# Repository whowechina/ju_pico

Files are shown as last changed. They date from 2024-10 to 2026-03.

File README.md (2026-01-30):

# Ju Pico - Jubeat Style Mini Controller
[点这里可以切换到中文版](README_CN.md)

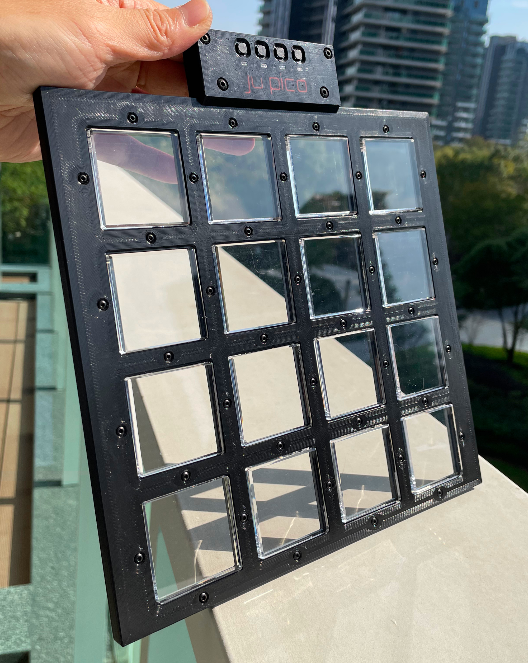
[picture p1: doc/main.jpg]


Features:
* There're two versions. Ju Pico is designed for 15.6" portable monitor, Ju Pico+ is designed for 21.5" monitor.
* It's small but closely replicates the feel of the arcade.
* Can be placed in 4 different orientations (rotations).
* Command line for configurations.
* All source files open.

Thanks to many respectful guys/companies who made their tools or materials free or open source (KiCad, OnShape, InkScape, Raspberry things).

Special thanks to community projects and developers.
And also these projects:
* RP_Silicon_KiCad: https://github.com/HeadBoffin/RP_Silicon_KiCad
* Type-C: https://github.com/ai03-2725/Type-C.pretty

## My Other Projects
You can check out my other cool projects.

           

* Popn Pico: https://github.com/whowechina/popn_pico
* IIDX Pico: https://github.com/whowechina/iidx_pico
* IIDX Teeny: https://github.com/whowechina/iidx_teeny
* Chu Pico: https://github.com/whowechina/chu_pico
* Mai Pico: https://github.com/whowechina/mai_pico
* Diva Pico: https://github.com/whowechina/diva_pico
* AIC Pico: https://github.com/whowechina/aic_pico
* Groove Pico: https://github.com/whowechina/groove_pico
* Geki Pico: https://github.com/whowechina/geki_pico
* Musec Pico: https://github.com/whowechina/musec_pico
* Ju Pico: https://github.com/whowechina/ju_pico

## **Disclaimer** ##
I made this project in my personal time with no financial benefit or sponsorship. I will continue to improve the project. I have done my best to ensure that everything is accurate and functional, there's always a chance that mistakes may occur. I cannot be held responsible for any loss of your time or money that may result from using this open source project. Thank you for your understanding.

## About the License
It's CC-NC. So DIY for yourself and for your friend, don't make money from it. And plagiarism that doesn’t even dare to mention the original author is not acceptable. Please note that pooling orders and group buying for raw materials is acceptable. Selling off any leftover components without profit is also acceptable.

If you're interested in buying from me, or for commercial use, please contact me (Discord, QQ group, Wechat group or leave your contact in issue section).

## My Discord Invitation
https://discord.gg/M8f2PPQFEA

## HOW TO BUILD JU PICO
### PCB and Components
* Go JLCPCB and make order with the gerber zip files (latest `Production\PCB\ju_io_xxx.zip` and `Production\PCB\ju_button_xxx.zip`), regular FR-4 board, black color, **1.6mm** thickness. For Ju Pico+, please use `button215` version.
* 1x Raspberry Pico Pi Pico or pin-to-pin compatible clones (U1).  
  https://www.raspberrypi.com/products/raspberry-pi-pico
* 1x USB Type-C socket (918-418K2023S40001 or KH-TYPE-C-16P)
* 4x WS2812B-3528 RGB LEDs.
* 4x Alps SKPMAPE010 6.0×5.9mm tactile switch in black, Panasonic EVQP1K05M works too, but it only comes in a white version.  
  https://tech.alpsalpine.com/e/products/detail/SKPMAPE010/
* 1x 0603 0.1uF (0.1~1uF all fine) capacitor (C1).
* 2x 0603 5.1kohm resistors (R1, R2) for the USB.
* 8x JST-SH1.0 5-pin SMD connectors (J1 to J4 on IO PCB, and 4 others on button PCBs).
* 1x JST-SH1.0 3-pin SMD connector (J5), optional for future HID light expansion.
* 4x JST-SH1.0 dual-end 5-pin cables (pin 1 to pin 1 mapping): 2 cables of 20cm length, and 2 cables of 30cm length.
* 64x Silicone rubber buttons, **6mm\*7mm**, **4mm** height, with 2 legs. Buy soft (lower actuation force) ones if possible. It looks like this:  
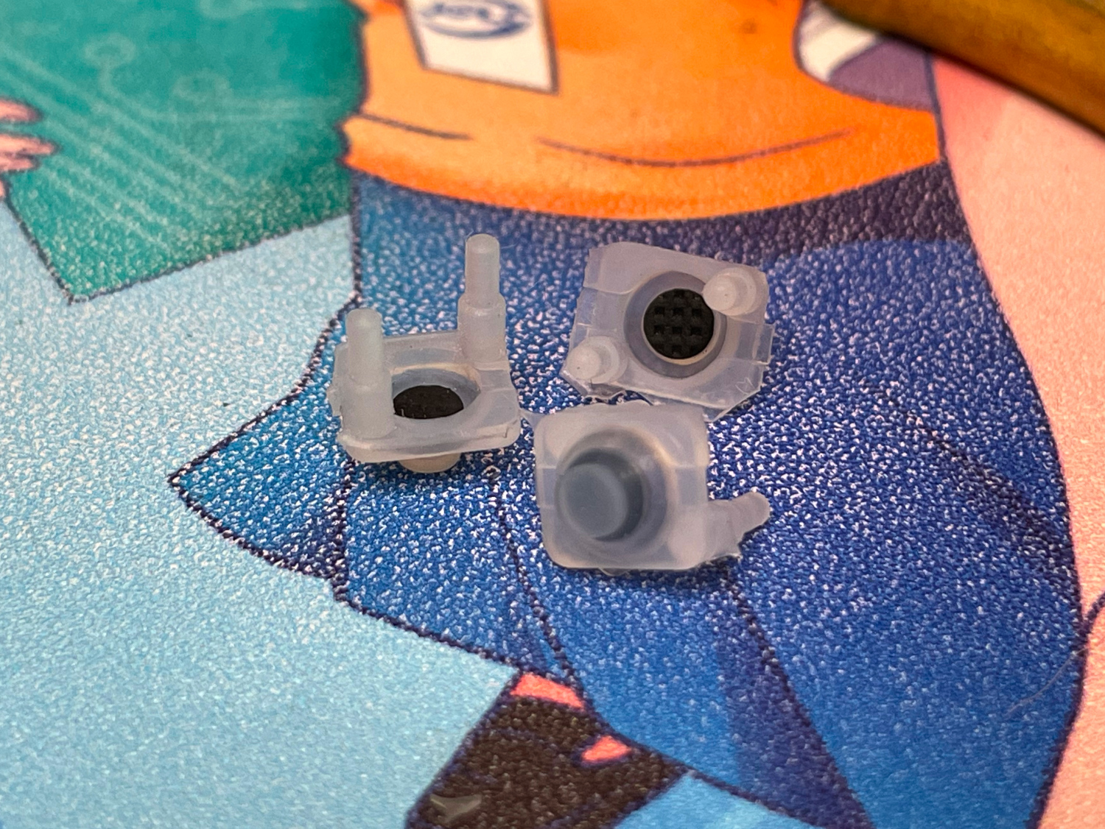
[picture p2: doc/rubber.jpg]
  
* This is how the I/O board looks after soldering.  
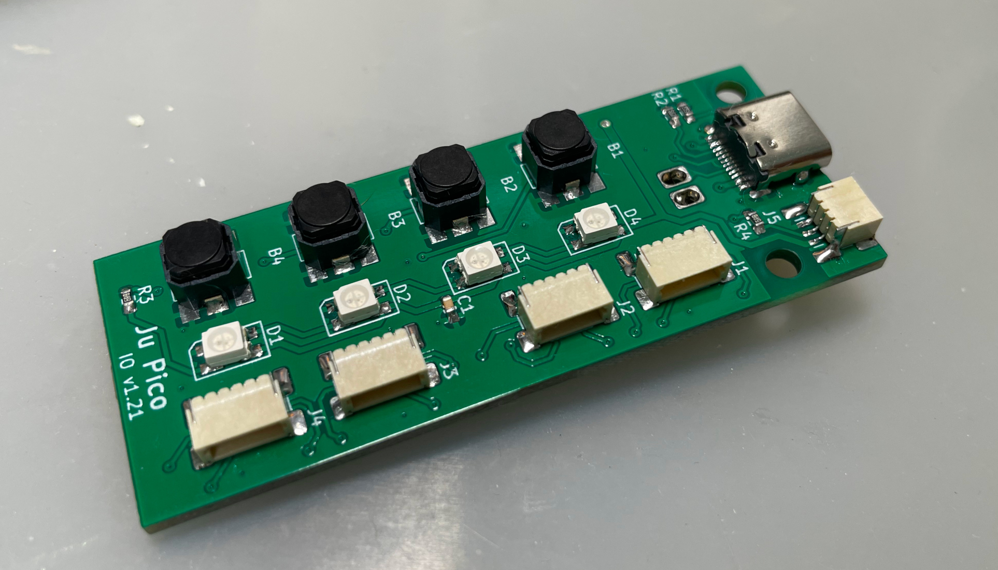
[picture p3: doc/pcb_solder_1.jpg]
    
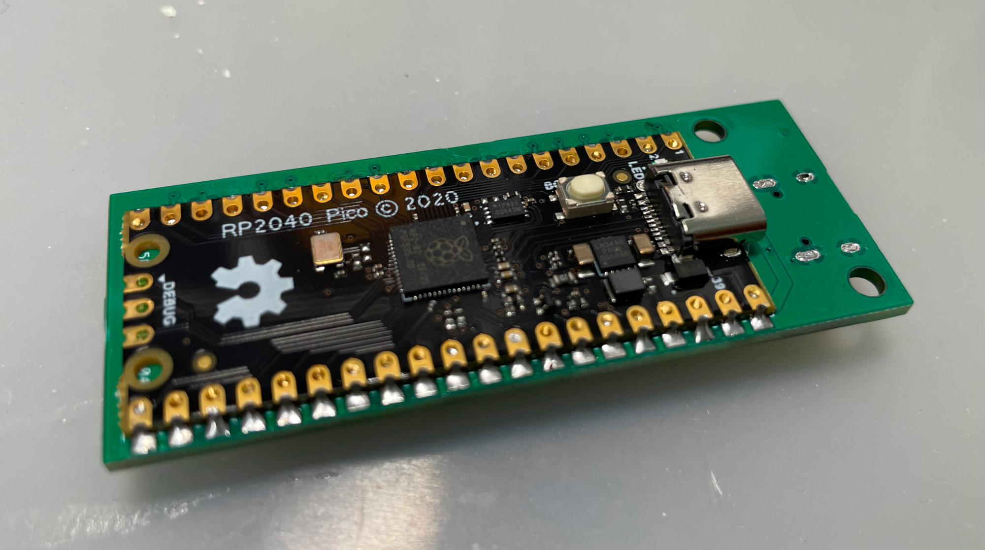
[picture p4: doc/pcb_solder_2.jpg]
  
* Becareful of 2 pin holes. It's a common oversight to either forget to solder them or to leave air bubbles during the process. To avoid this, solder slowly from one side of the hole, using minimal solder wire and a generous amount of flux.  
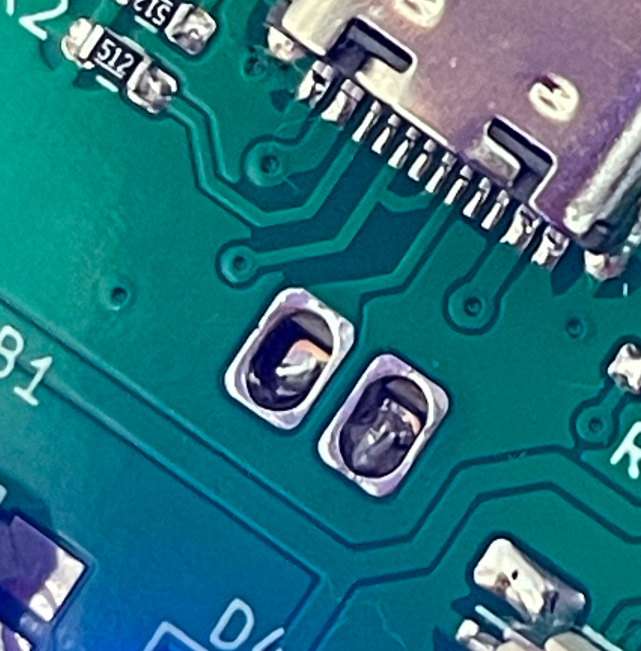
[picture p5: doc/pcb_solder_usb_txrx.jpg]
  

### Test the IO PCB
* You can test the PCB now, put the firmware in IO PCB.
* All 4 RGB LEDs should light up in a rainbow pattern.
* LEDs responds to the the leftmost button, indicating current orientation.
* Ju Pico should be recognized as a USB HID device, here's the test page.  
  https://greggman.github.io/html5-gamepad-test/
* Connect the 4 button PCBs to the IO PCB, and use one rubber button to test the button contacts on the PCB, you'll see the status change in said HID test page.

### Button Cap
Ju Pico has 16 buttons, so you need to order 16 button caps.

They are made of clear acrylic, measuring 40mm x 40mm with a corner radius of 1-1.5mm and a thickness of 5mm. All these parameters are IMPORTANT and should be followed closely. A polished bevel of **1.5-2mm** on top edges gives a better feel.

Here's what it looks like.  
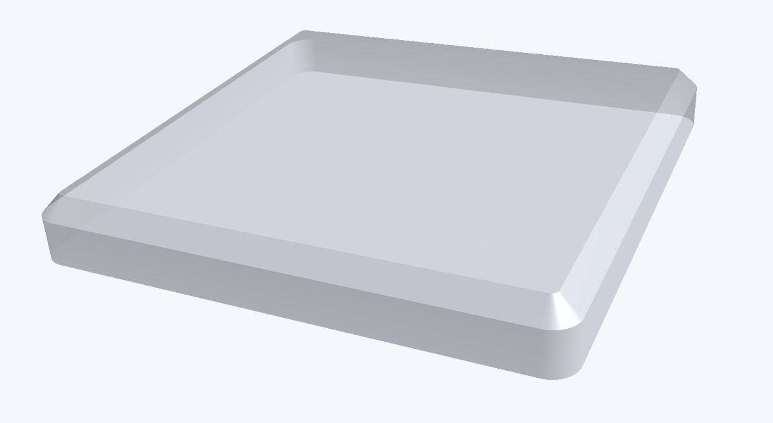
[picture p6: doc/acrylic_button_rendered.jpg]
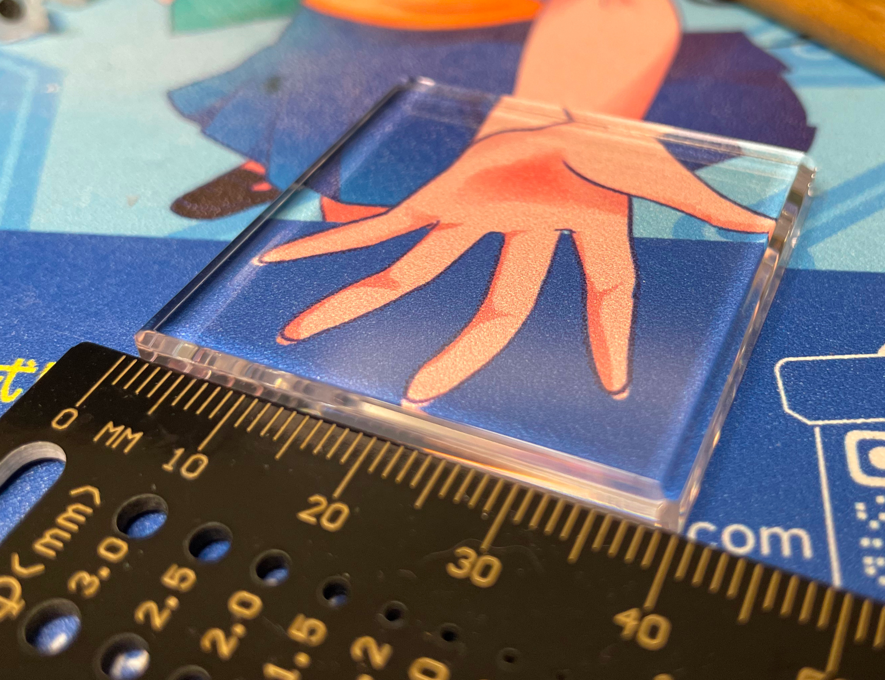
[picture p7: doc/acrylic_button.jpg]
 

### 3D Printing
#### Printing parameters
* PLA (recommended) or PETG.
* Layer height: 0.2mm.
* Walls: 5.
* Infill: >=80%.
* Support: Yes, better with special support material.
* Glue on bed: Yes, it prevents corner warping.
* Files are always in millimeter unit, not inch.

#### Parts
* Note: if you want to build Ju Pico+, please use the files with "+" in the filename.
* You have 3 options for the Frame part, heatset insert version is recommended.
  * Screws are threaded into heatset inserts: `Production\3DPrint\ju_pico_frame_inserts.stl`, black. Please install the heat-set inserts first.
  * Screws are directly threaded into the printed material: `Production\3DPrint\ju_pico_frame.stl`, black. Assembly is easier but the screws may wear out the material over time.
  * Screws are threaded into the hex nuts: `Production\3DPrint\ju_pico_frame_hexnut.stl`, black. Assembly is a bit more complicated but the screws won't wear out the material.
* Panel: `Production\3DPrint\ju_pico_panel.stl`, black, print up-side-down with support (use special support material if possible).
* Banner: `Production\3DPrint\ju_pico_banner.3mf`, multi-color, print up-side-down, mainbody is black, LED windows are transparent, logos are red or orange, use special support material if possible.
* 16x Button Seats: `Production\3DPrint\ju_pico_button_seat_*.stl`, black, print up-side-down to avoid overhanging. Choose the one that fits your button cap.
* All together, they look like these.  
  
* Note: Files with "bambu" in the name are project files prepared for Bambu Studio.
* CAUTION: Do not mix use files before and after December 2024, as I made some incompatible changes in early December 2024.

### CNC Aluminum Processing (Optional, only available for Ju Pico)
* If you're into that sleek metal look and don't mind splurging a bit, you can get the frame, panel, and banner parts CNC machined from aluminum.
* Sandblasting and anodizing can be chosen to make it look even better.
* The STEP files are in `Production\CNC` folder, the 2D DWG file is the thread tapping drawing for the frame part.
* You need to 3D print `Production\3DPrint\ju_pico_led_diffuser_for_cnc.stl` for LED diffusion, use transparent material.

### Assembly
#### Other Materials Needed
1. Clear soft/flexible glue or UV curing glue. WARNING: Avoid using any cyanoacrylate-based glue, such as 502. Any glue with a similar smell should also be avoided, as they will leave white smoke marks on the acrylic.
2. 40x **M2\*6mm** (for regular frame) or **M2\*7mm** (for hex nut frame or heatset insert frame) screws, black, for the panel.
3. 4x **M3\*8mm** screws, black, for the banner.
4. 40x **M2** hex nuts (only for hex nut frame version).
5. 40x **M2\*3mm\*3mm** heat-set inserts (only for heatset insert frame version).

### Step by Step
1. Glue the button bodies to the button seats. Be careful don't let the glue ruin the acrylic. See the "Caution" section below for more details.  
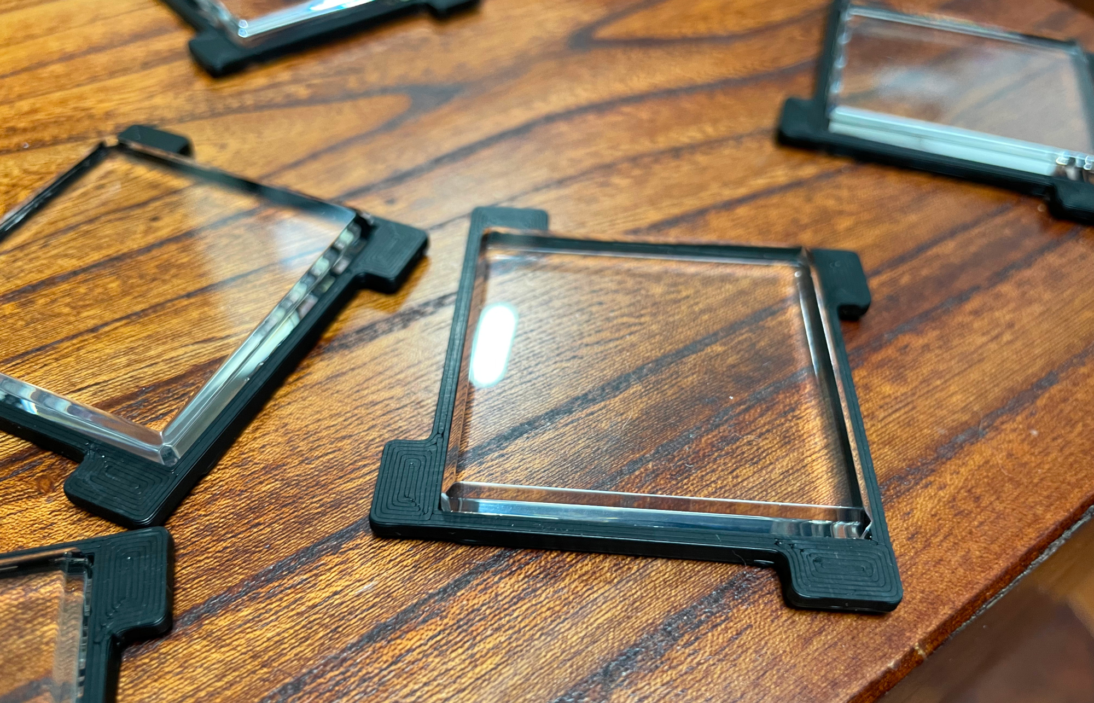
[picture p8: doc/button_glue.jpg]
   
2. Insert the silicone rubber buttons into the button PCBs. Ensure to pull the legs so that the button sits perfectly flush against the PCB.  
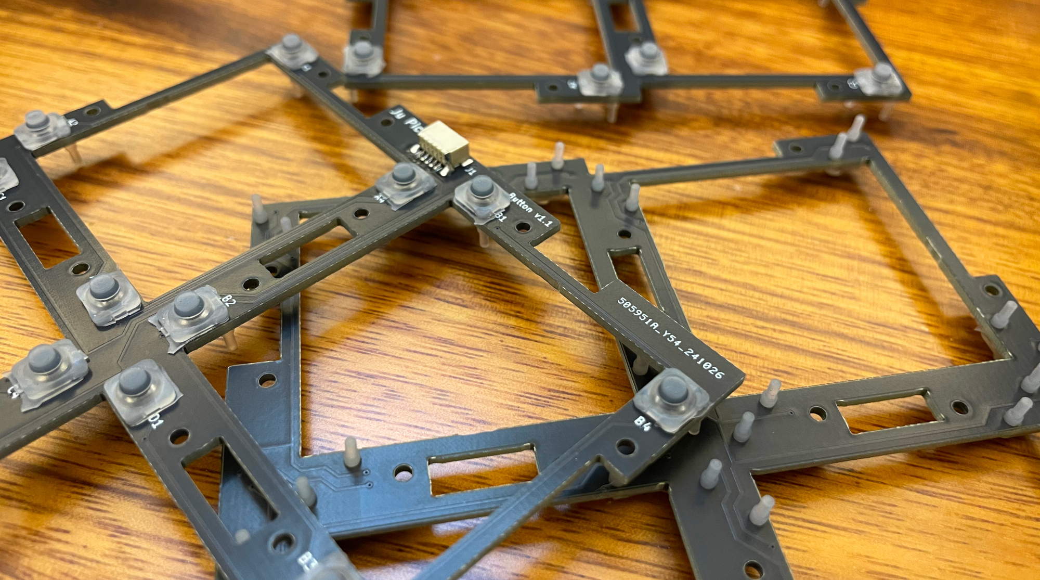
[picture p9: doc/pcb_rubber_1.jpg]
   
3. Use a sharp side cutter to trim the legs of the rubber buttons so that they are flush with the PCB, leaving no protruding parts.  
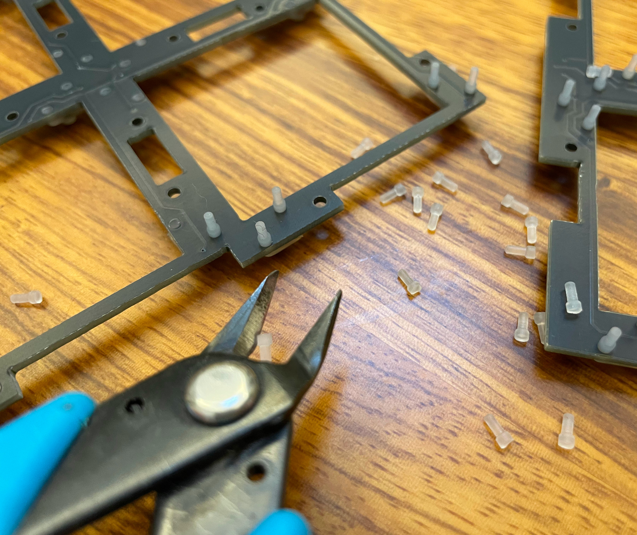
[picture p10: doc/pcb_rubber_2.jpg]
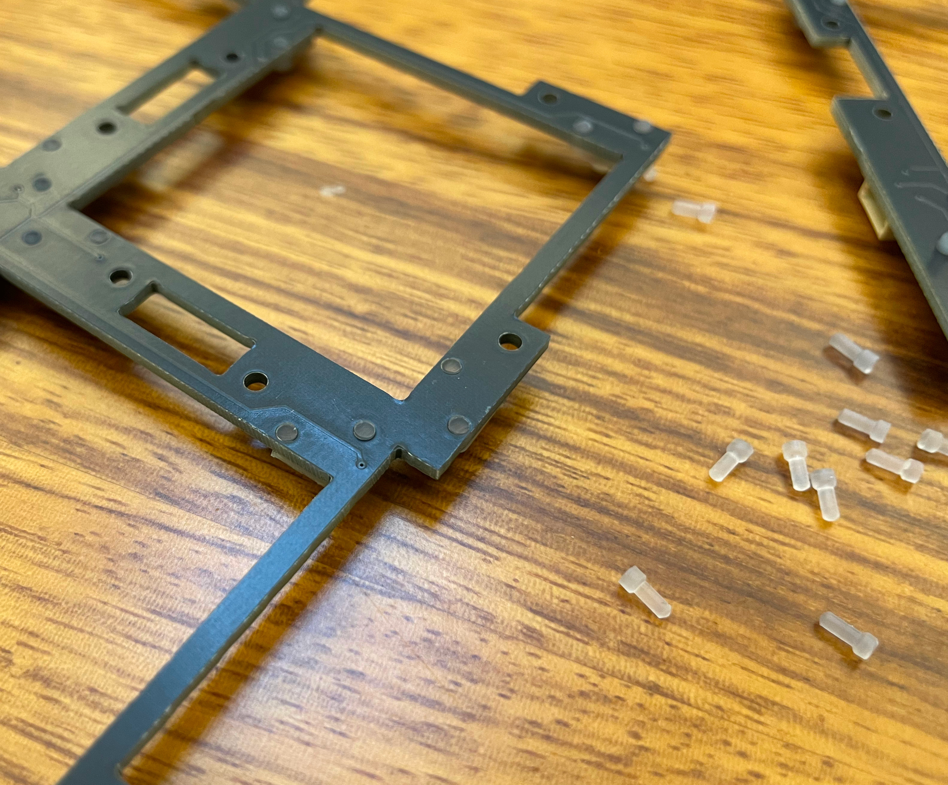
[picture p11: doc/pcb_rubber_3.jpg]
    
4. Put button PCBs into the frame part and use the cables to connect them to the IO PCB.  
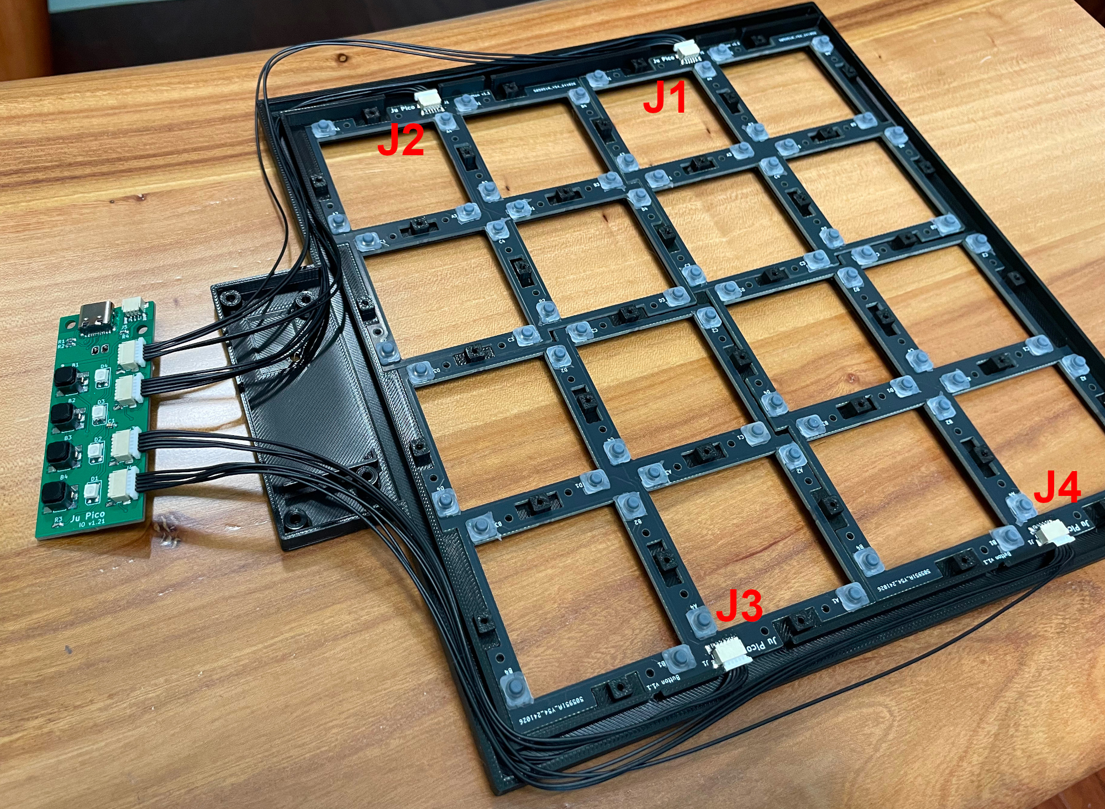
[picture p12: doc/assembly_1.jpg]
   
5. Arrange the cables and make them fit in the cable slots.  
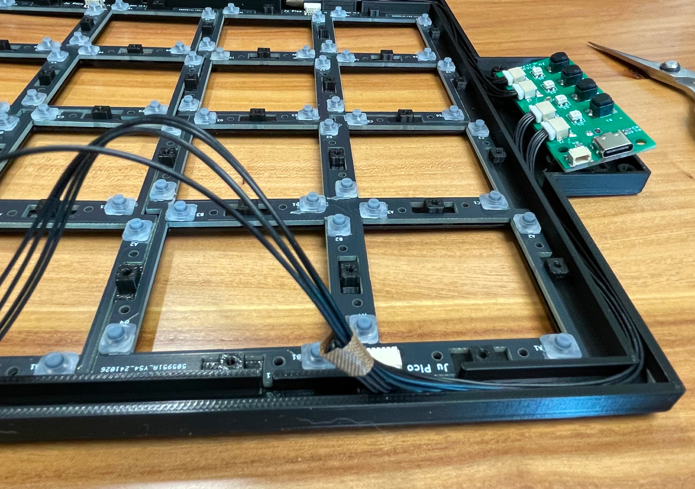
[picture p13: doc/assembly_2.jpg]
   
6. If you arrange them well, it will look very neat.  
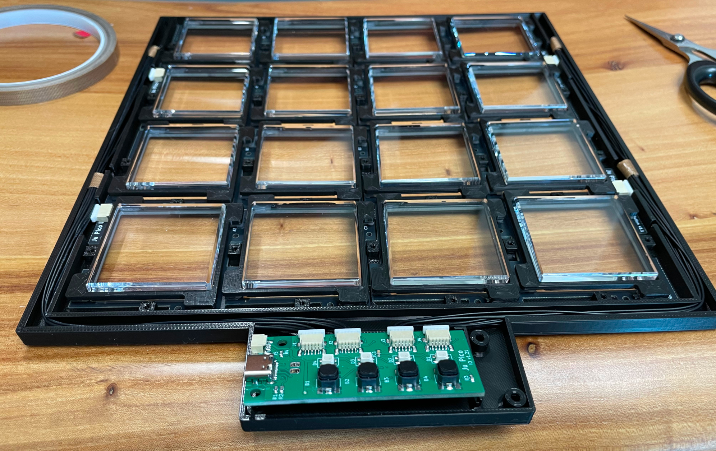
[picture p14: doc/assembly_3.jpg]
   
7. Gently put the finished buttons onto the button PCBs.  
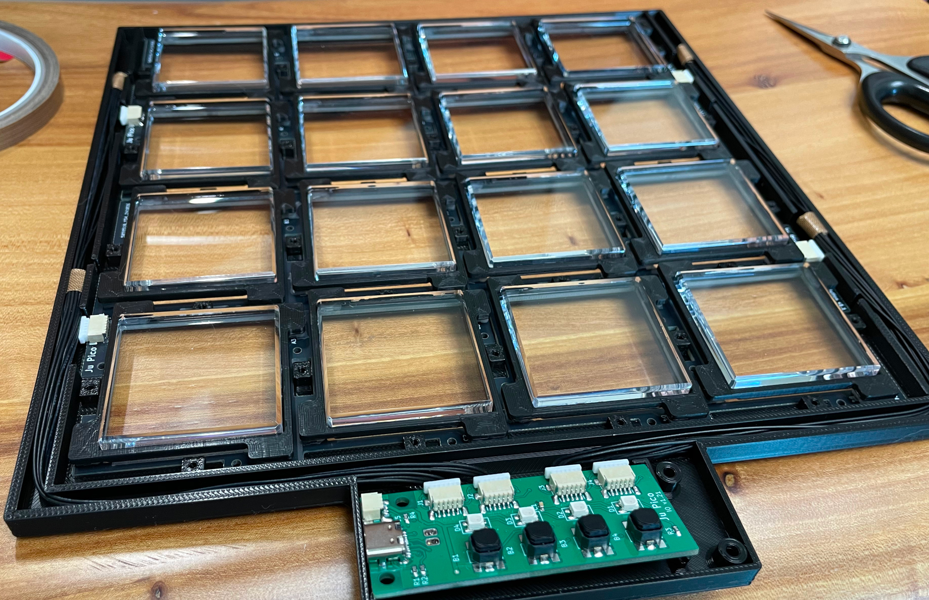
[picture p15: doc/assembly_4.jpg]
   
8. Attach the panel part and secure it with (a lot) M2 screws. Be very careful, 3D print materials are fragile and sensitive to heat. So screw slowly, especially when using a power screwdriver, as the threads in the plastic can easily strip. Lastly put on the banner part and use M3 screws to fix it. And there you go!  
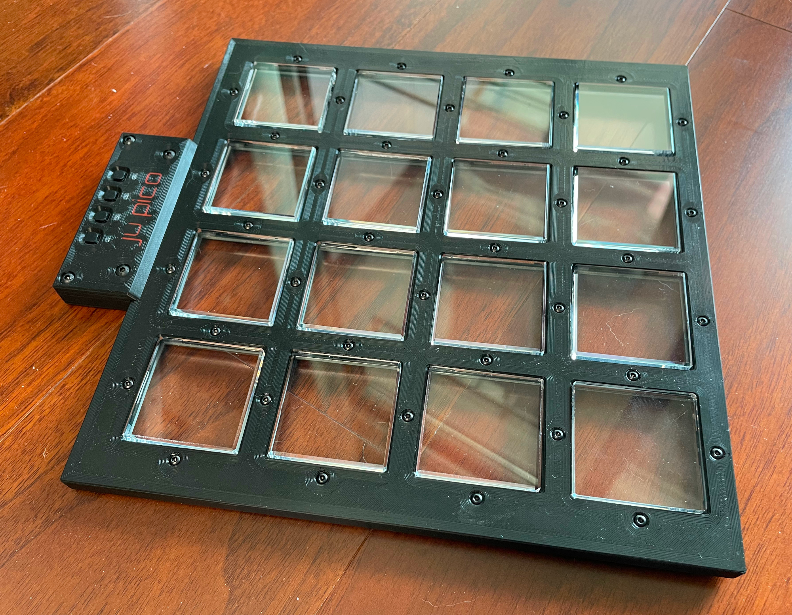
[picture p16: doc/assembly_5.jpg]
   

#### Caution
Each 3D printer and filament has its own tolerance, as does the acrylic cutting service. Therefore, I've created multiple versions of the button seat. You can try them and select the one that fits your acrylic button cap perfectly.

## Firmware
* UF2 file is in `Production\Firmware` folder.
* For the new build, hold the BOOTSEL button while connect the USB to a PC, there will be a disk named "RPI-RP2" showed up. Drag the UF2 firmware binary file into it. That's it. There's a small hole at the bottom side of the Ju Pico, it is facing right to the BOOTSEL button.
* If it's already running Ju Pico firmware, you can either use "update" in command line or hold down at least 4 buttons while connecting to USB to enter update mode.
* To access the command line, you can use this Web Serial Terminal to connect to the USB serial port of the Ju Pico. (Note: "?" is for help)  
  https://googlechromelabs.github.io/serial-terminal/

### Usage
* Attach the Ju Pico to a 15.6-inch portable monitor (or Ju Pico+ to a 21.5-inch monitor) using VHB residue-free adhesive tape. Use 3 to 4 small pieces on the monitor's frame, but avoid placing any on the screen. Position it in the orientation that best suits your needs.
* Press the auxiliary button closest to letter 'j" of the logo "Ju Pico" together with the top left main button in the actual placement to set button order that matches your orientation. Analog joystick position in HID report indicates which side the logo should be. You can use the following website to see the joystick status.  
  https://greggman.github.io/html5-gamepad-test/

## CAD Source File
I'm using OnShape free subscription. It's powerful but it can't archive original designs to local, so I can only share the link here. STL/DXF/DWG files are exported from this online document.  
  https://cad.onshape.com/documents/c70fd7c4cb933fd28c4678b3/w/277dab41d8d592c817e9419a/e/e9cf38ee55134a09b2deb5d6

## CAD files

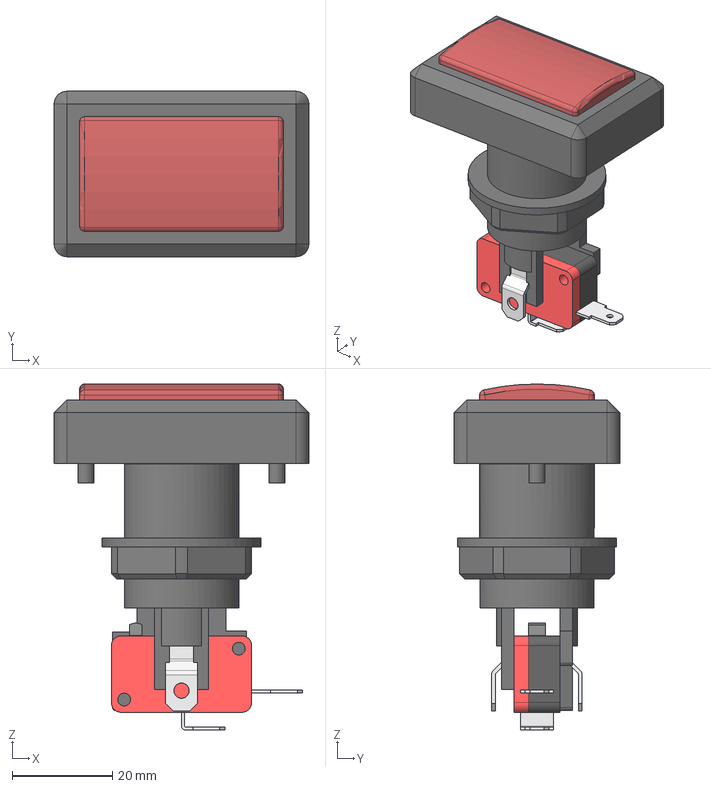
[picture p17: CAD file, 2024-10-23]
PCB/Touch/3dmodels/Credit Button Assy (Groovy).step
50.8 x 33.0 x 69.0 mm
Button
Nut
Switch

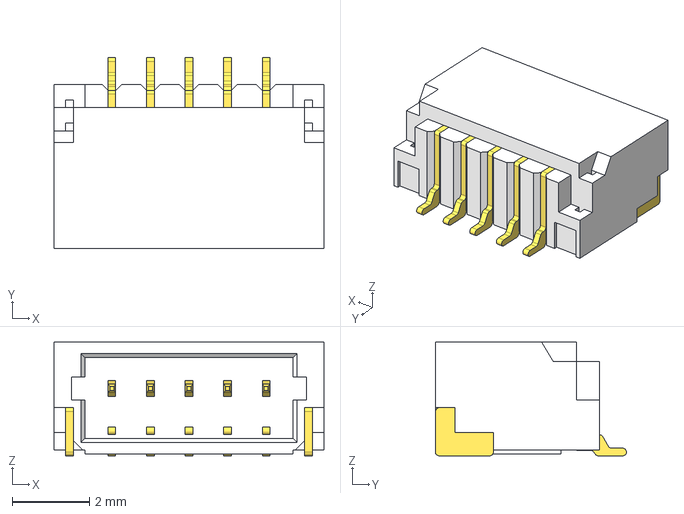
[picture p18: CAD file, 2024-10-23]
PCB/Button/3dmodels/SM5B-SRSS-TB.step
7.00 x 4.95 x 2.95 mm

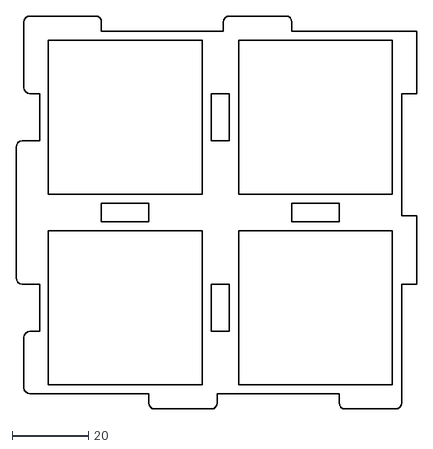
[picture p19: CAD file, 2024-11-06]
PCB/Button/PCB - PCB Cut.dxf
105.2 x 103.2

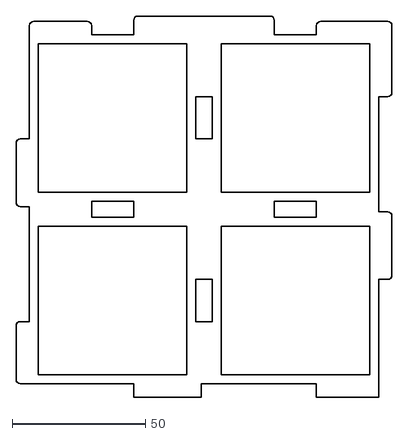
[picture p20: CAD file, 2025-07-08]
PCB/Button215/PCB+ - PCB Cut 215.dxf
141.1 x 143.1

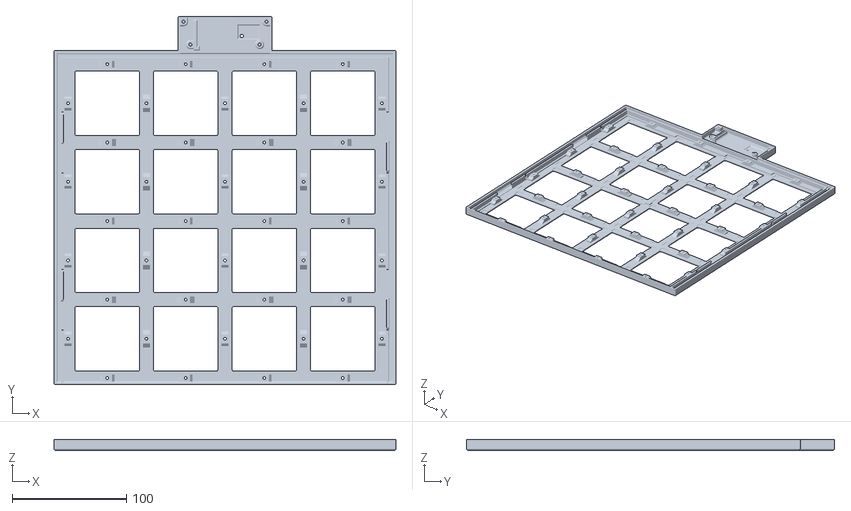
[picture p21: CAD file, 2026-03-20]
Production/3DPrint/ju_pico+_frame_inserts.stl
299.6 x 322.6 x 9.20

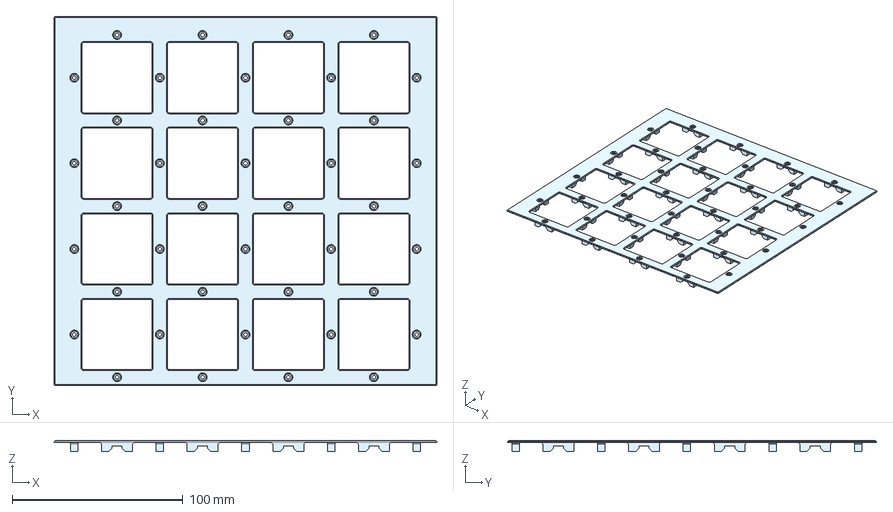
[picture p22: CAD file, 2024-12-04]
Production/CNC/ju_pico_cnc_panel.step
224.0 x 216.0 x 6.20 mm

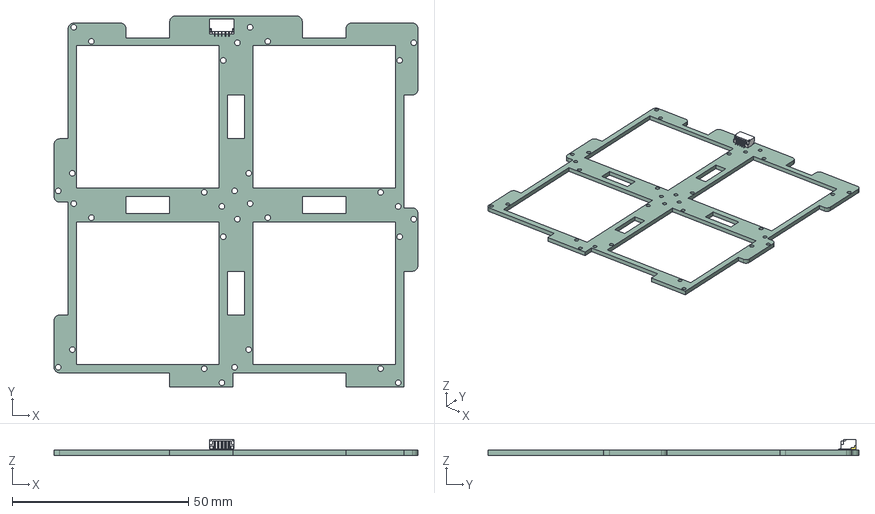
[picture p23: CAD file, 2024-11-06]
PCB/Button/ju_button_3d.step
103.2 x 105.2 x 4.65 mm
SMxB-SRSS-TB
ju_button_PCB

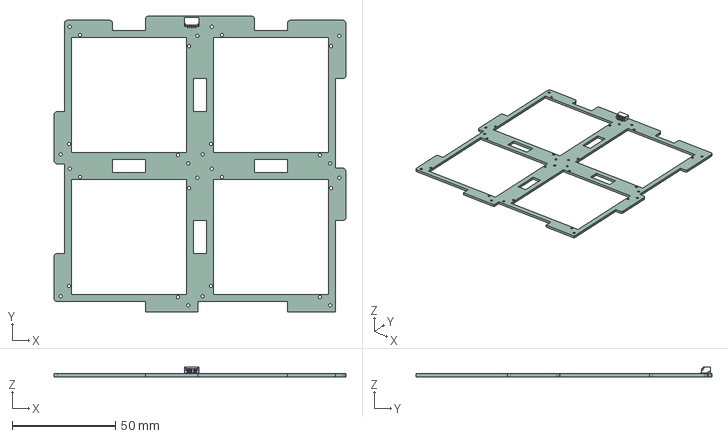
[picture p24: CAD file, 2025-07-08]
PCB/Button215/ju_button215_3d.step
141.1 x 143.1 x 4.59 mm
SM5B-SRSS-TB
ju_button215_PCB

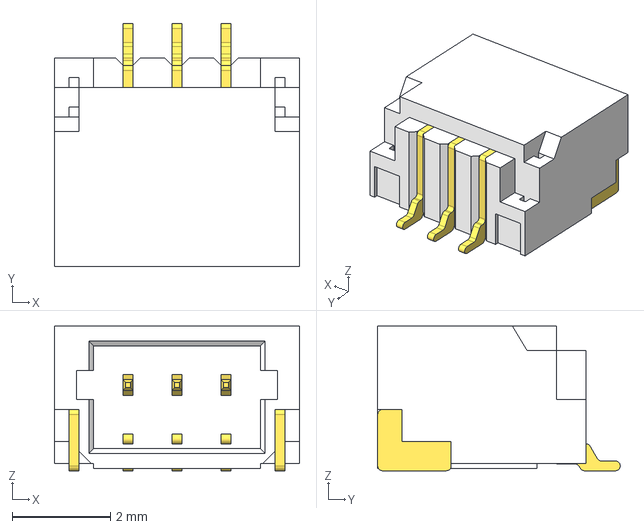
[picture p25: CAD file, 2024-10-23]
PCB/IO/3dmodels/SM3B-SRSS-TB.step
5.00 x 4.95 x 2.95 mm

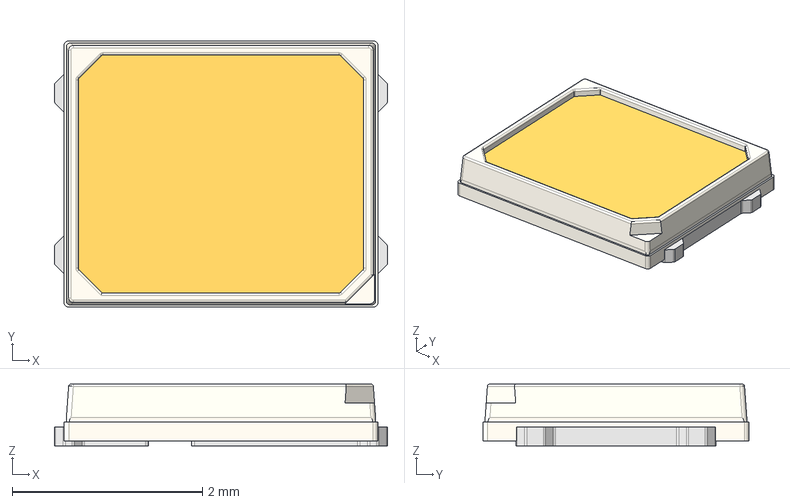
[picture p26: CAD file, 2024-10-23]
PCB/Touch/3dmodels/J 2835.step
3.50 x 2.80 x 0.65 mm

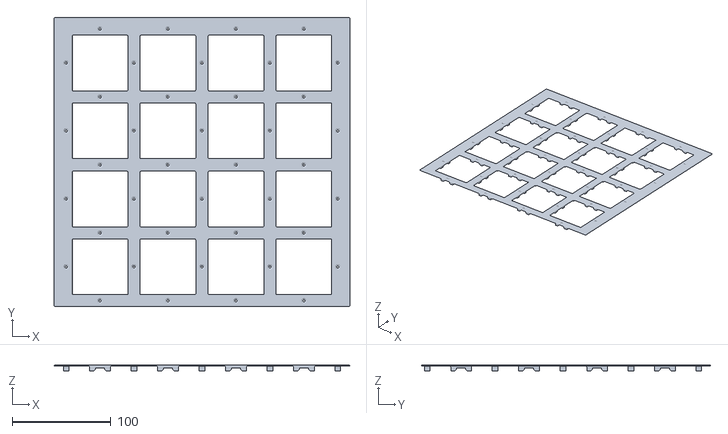
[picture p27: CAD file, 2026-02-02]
Production/3DPrint/ju_pico+_panel.stl
299.6 x 292.6 x 6.20

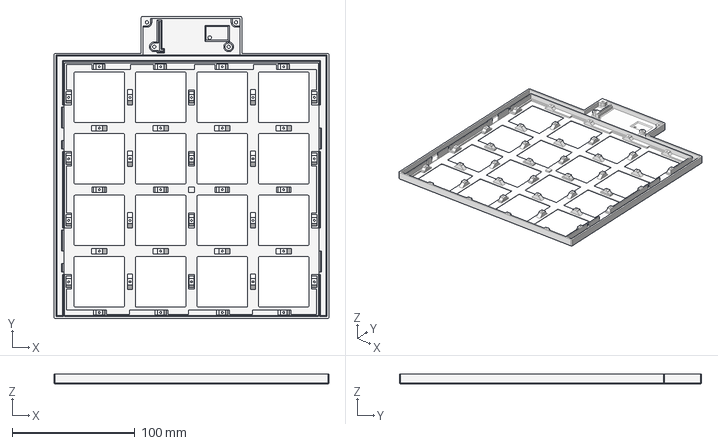
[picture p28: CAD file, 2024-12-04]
Production/CNC/ju_pico_cnc_frame.step
224.0 x 246.0 x 8.20 mm

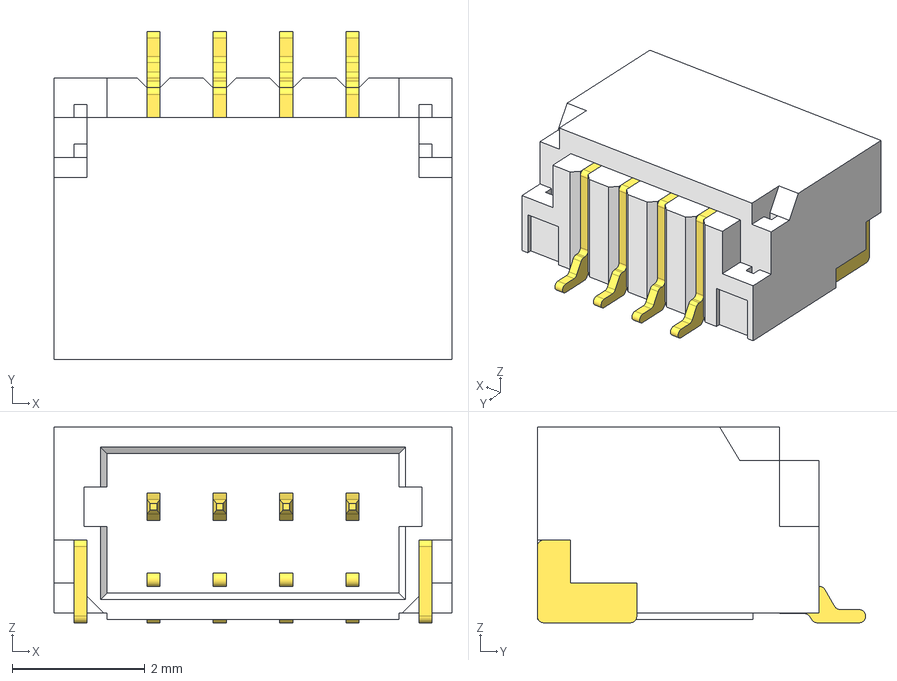
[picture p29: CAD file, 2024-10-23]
PCB/IO/3dmodels/SM4B-SRSS-TB.step
6.00 x 4.95 x 2.95 mm

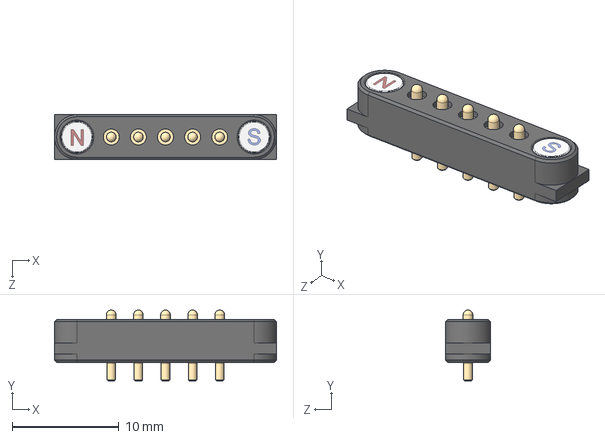
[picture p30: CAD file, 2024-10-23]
PCB/Touch/3dmodels/Magnetic Pogo Connector 5 Pin (Type 2).STEP
20.8 x 6.65 x 4.20 mm

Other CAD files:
PCB/Touch/3dmodels/iidx_keycap_main_step.stp
PCB/Button215/3dmodels/SM5B-SRSS-TB.step
Production/3DPrint/ju_pico+_button_seat_55.6mm.stl
PCB/Touch/3dmodels/EVQ-P1D05M.stp
PCB/Touch/3dmodels/Kailh LP Choc PC Keycap.step
PCB/Touch/3dmodels/Magnetic Pogo Connector 5 Pin (F).STEP
PCB/Touch/3dmodels/Magnetic Pogo Connector 5 Pin (Type 1).STEP
PCB/Touch/3dmodels/Magnetic Pogo Connector 5 Pin (Type 3).STEP
PCB/Touch/3dmodels/Magnetic Pogo Connector 5 Pin (Type 4).STEP
PCB/Touch/3dmodels/SKPMAM.STEP
PCB/Touch/3dmodels/SMD WS2812B-3535.step
PCB/Touch/3dmodels/SW_Hotswap_Kailh_Choc_V1.stp
PCB/Touch/3dmodels/SW_Hotswap_Kailh_MX.stp
PCB/Touch/3dmodels/SW_Kailh_Choc_V1.stp
PCB/Touch/3dmodels/Tact Switch 4.5mm SMT.step
PCB/Touch/3dmodels/User Library-PTS645SL95SMTR92-LFS.STEP
PCB/Touch/3dmodels/User Library-WS2812-2020.step
PCB/Touch/3dmodels/User Library-WS2812-4020.step
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

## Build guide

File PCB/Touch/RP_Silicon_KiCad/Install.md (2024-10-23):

# Install KiCad libraries

## Manage Symbol Libraries

Accessed from the Preferences menu, add a new line with the +, give it a name and use the folder icon to point to the directory/folder where you have KiCadLibraries.

Manage Symbol Libraries screen shot


## Manage Footprint Libraries

Ditto! Accessed from the Preferences menu, add a new line with the +, give it a name and use the folder icon to point to the directory/folder where you have KiCadLibraries.

Manage Footprint Libraries screen shot


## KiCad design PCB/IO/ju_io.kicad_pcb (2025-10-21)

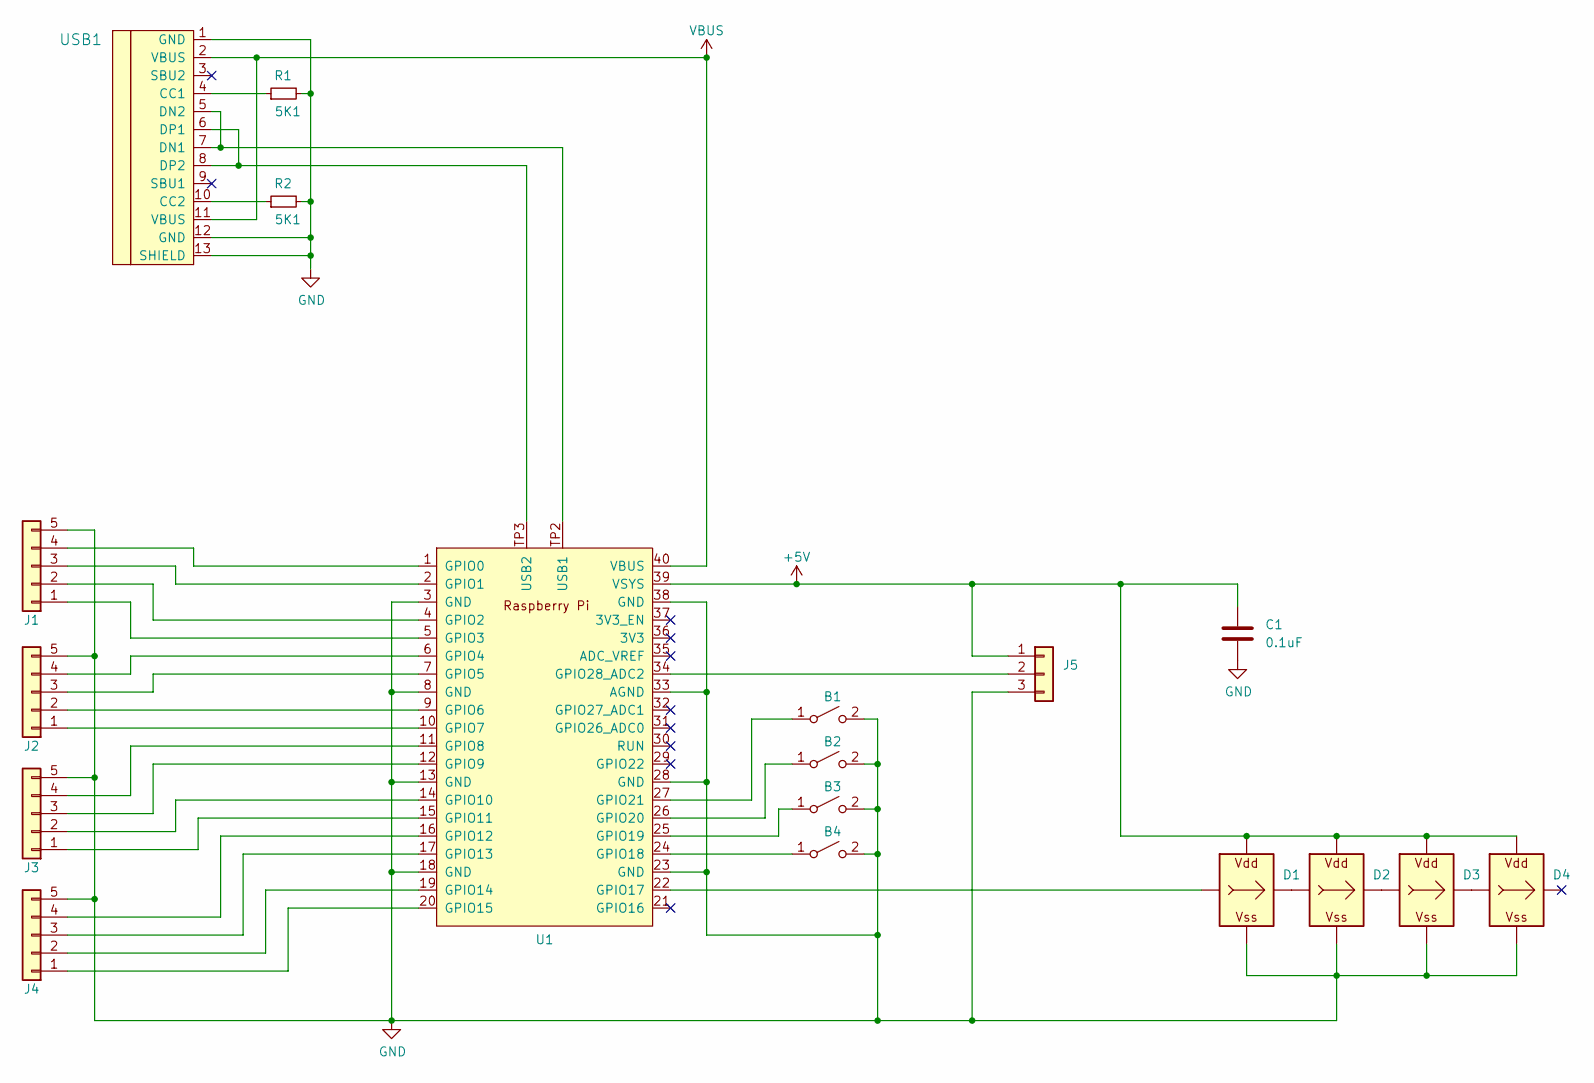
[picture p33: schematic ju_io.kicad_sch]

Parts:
B1, B2, B3, B4: SW_SPST; EVQP1K05M
C1: 0.1uF; C_0603_1608Metric_Pad1.08x0.95mm_HandSolder
D1, D2, D3, D4: WS2812B_Unified; WS2812B-2835
J1, J2, J3, J4: Conn_01x05; SH1.0_5P
J5: Conn_01x03; SH1.0_3P
R1, R2: 5K1; R_0603_1608Metric_Pad0.98x0.95mm_HandSolder; LCSC C23186
U1: PiPico_No_SWD; RPi_Pico_SMD_Pins_No_SWD_No_Text
USB1: U262-161N-4BVC11; HRO-TYPE-C-31-M-12-Assembly; LCSC C319148

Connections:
+5V: C1.1, D1.V (VDD), D2.V (VDD), D3.V (VDD), D4.V (VDD), J5.1, U1.39 (VSYS)
GND: B1.2 (B), B2.2 (B), B3.2 (B), B4.2 (B), C1.2, D1.G (VSS), D2.G (VSS), D3.G (VSS), D4.G (VSS), J1.5, J2.5, J3.5, J4.5, J5.3, R1.2, R2.2, U1.3 (GND), U1.8 (GND), U1.13 (GND), U1.18 (GND), U1.23 (GND), U1.28 (GND), U1.33 (AGND), U1.38 (GND), USB1.1 (GND), USB1.12 (GND), USB1.13 (SHIELD)
unnamed: B1.1 (A), U1.27 (GPIO21)
unnamed: B2.1 (A), U1.26 (GPIO20)
unnamed: B3.1 (A), U1.25 (GPIO19)
unnamed: B4.1 (A), U1.24 (GPIO18)
unnamed: D1.I (In), U1.22 (GPIO17)
unnamed: D1.O (Out), D2.I (In)
unnamed: D2.O (Out), D3.I (In)
unnamed: D3.O (Out), D4.I (In)
unnamed: J1.1, U1.5 (GPIO3)
unnamed: J1.2, U1.4 (GPIO2)
unnamed: J1.3, U1.2 (GPIO1)
unnamed: J1.4, U1.1 (GPIO0)
unnamed: J2.1, U1.10 (GPIO7)
unnamed: J2.2, U1.9 (GPIO6)
unnamed: J2.3, U1.7 (GPIO5)
unnamed: J2.4, U1.6 (GPIO4)
unnamed: J3.1, U1.15 (GPIO11)
unnamed: J3.2, U1.14 (GPIO10)
unnamed: J3.3, U1.12 (GPIO9)
unnamed: J3.4, U1.11 (GPIO8)
unnamed: J4.1, U1.20 (GPIO15)
unnamed: J4.2, U1.19 (GPIO14)
unnamed: J4.3, U1.17 (GPIO13)
unnamed: J4.4, U1.16 (GPIO12)
unnamed: J5.2, U1.34 (GPIO28_ADC2)
unnamed: U1.TP2 (USB1), USB1.5 (DN2), USB1.7 (DN1)
unnamed: U1.TP3 (USB2), USB1.6 (DP1), USB1.8 (DP2)
unnamed: R1.1, USB1.4 (CC1)
unnamed: R2.1, USB1.10 (CC2)
VBUS: U1.40 (VBUS), USB1.2 (VBUS), USB1.11 (VBUS)

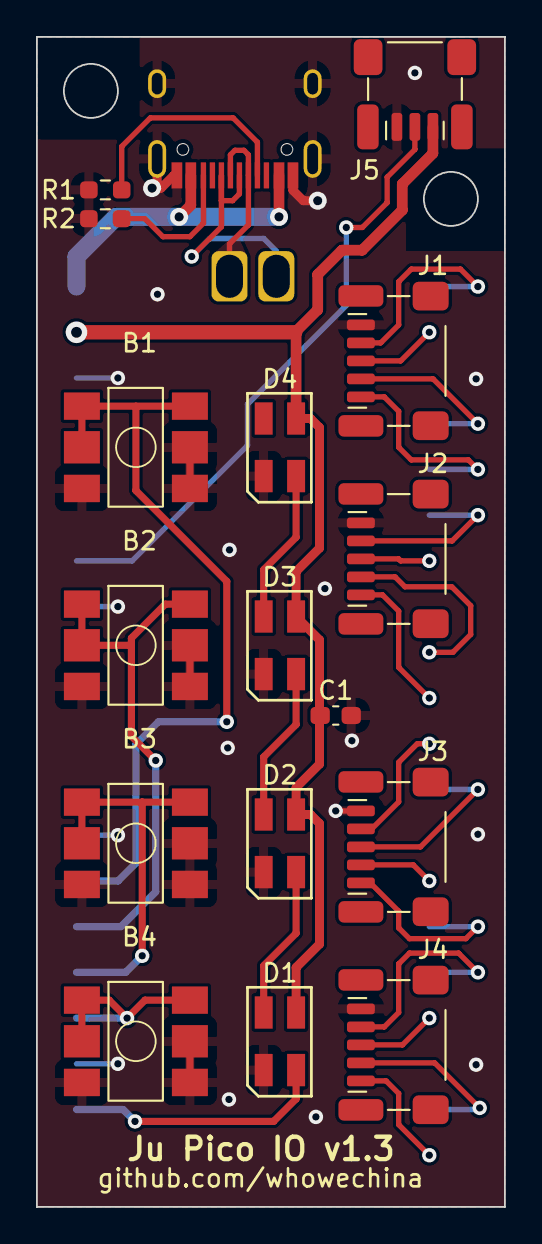
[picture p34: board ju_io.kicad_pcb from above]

Board: 2 copper layers, 26.0 x 65.0 mm, 18 parts (1 on the bottom side), 32 nets.

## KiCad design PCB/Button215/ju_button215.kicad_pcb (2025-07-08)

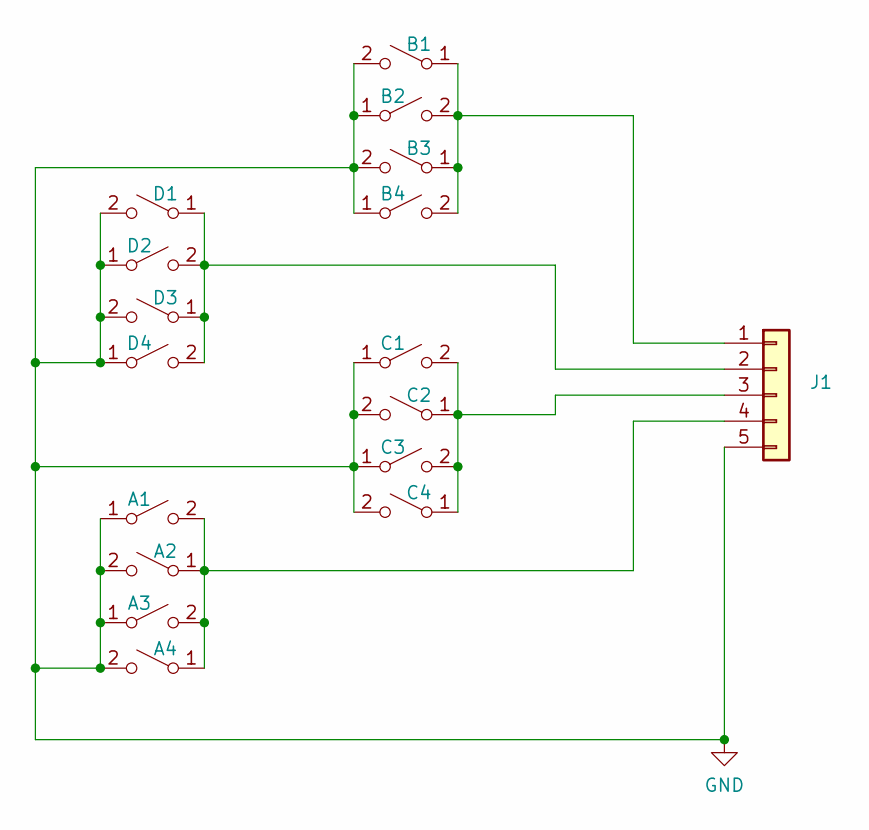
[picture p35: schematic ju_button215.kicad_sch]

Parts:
A1, A2, A3, A4: SW_SPST; JuRubber
B1, B2, B3, B4: SW_SPST; JuRubber
C1, C2, C3, C4: SW_SPST; JuRubber
D1, D2, D3, D4: SW_SPST; JuRubber
J1: Conn_01x05; SH1.0_5P

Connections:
GND: A1.1 (A), A2.2 (B), A3.1 (A), A4.2 (B), B1.2 (B), B2.1 (A), B3.2 (B), B4.1 (A), C1.1 (A), C2.2 (B), C3.1 (A), C4.2 (B), D1.2 (B), D2.1 (A), D3.2 (B), D4.1 (A), J1.5
unnamed: A1.2 (B), A2.1 (A), A3.2 (B), A4.1 (A), J1.4
unnamed: B1.1 (A), B2.2 (B), B3.1 (A), B4.2 (B), J1.1
unnamed: C1.2 (B), C2.1 (A), C3.2 (B), C4.1 (A), J1.3
unnamed: D1.1 (A), D2.2 (B), D3.1 (A), D4.2 (B), J1.2

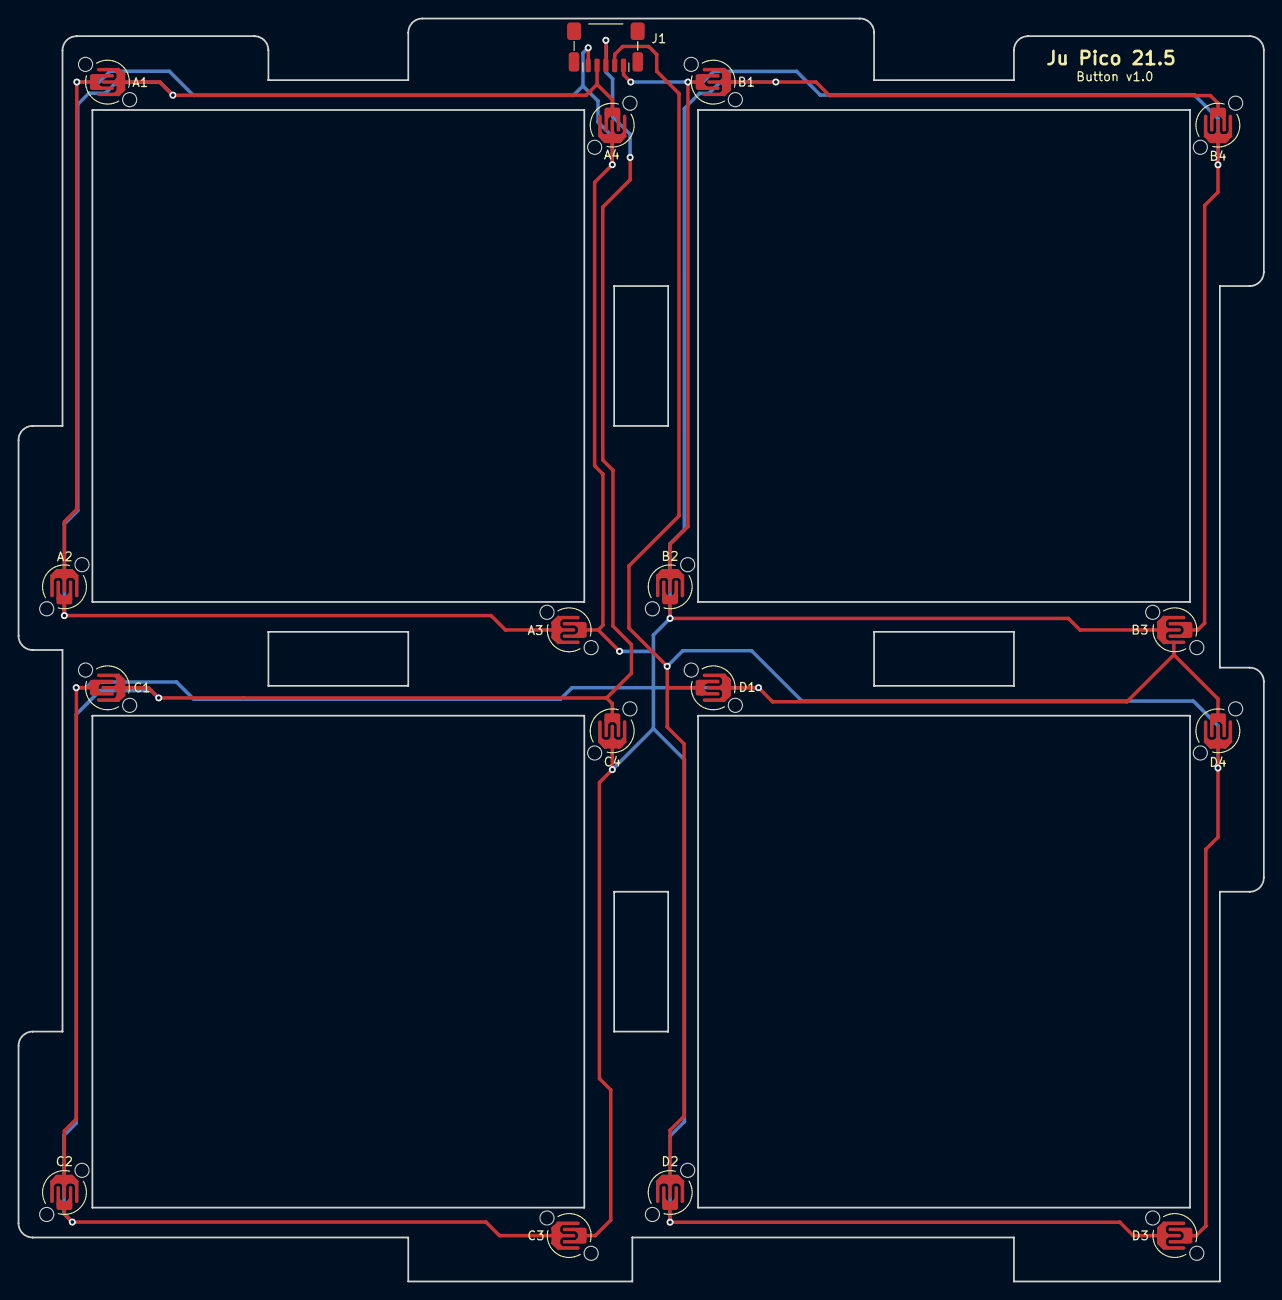
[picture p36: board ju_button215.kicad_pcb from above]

Board: 2 copper layers, 141.1 x 143.1 mm, 17 parts (0 on the bottom side), 5 nets.

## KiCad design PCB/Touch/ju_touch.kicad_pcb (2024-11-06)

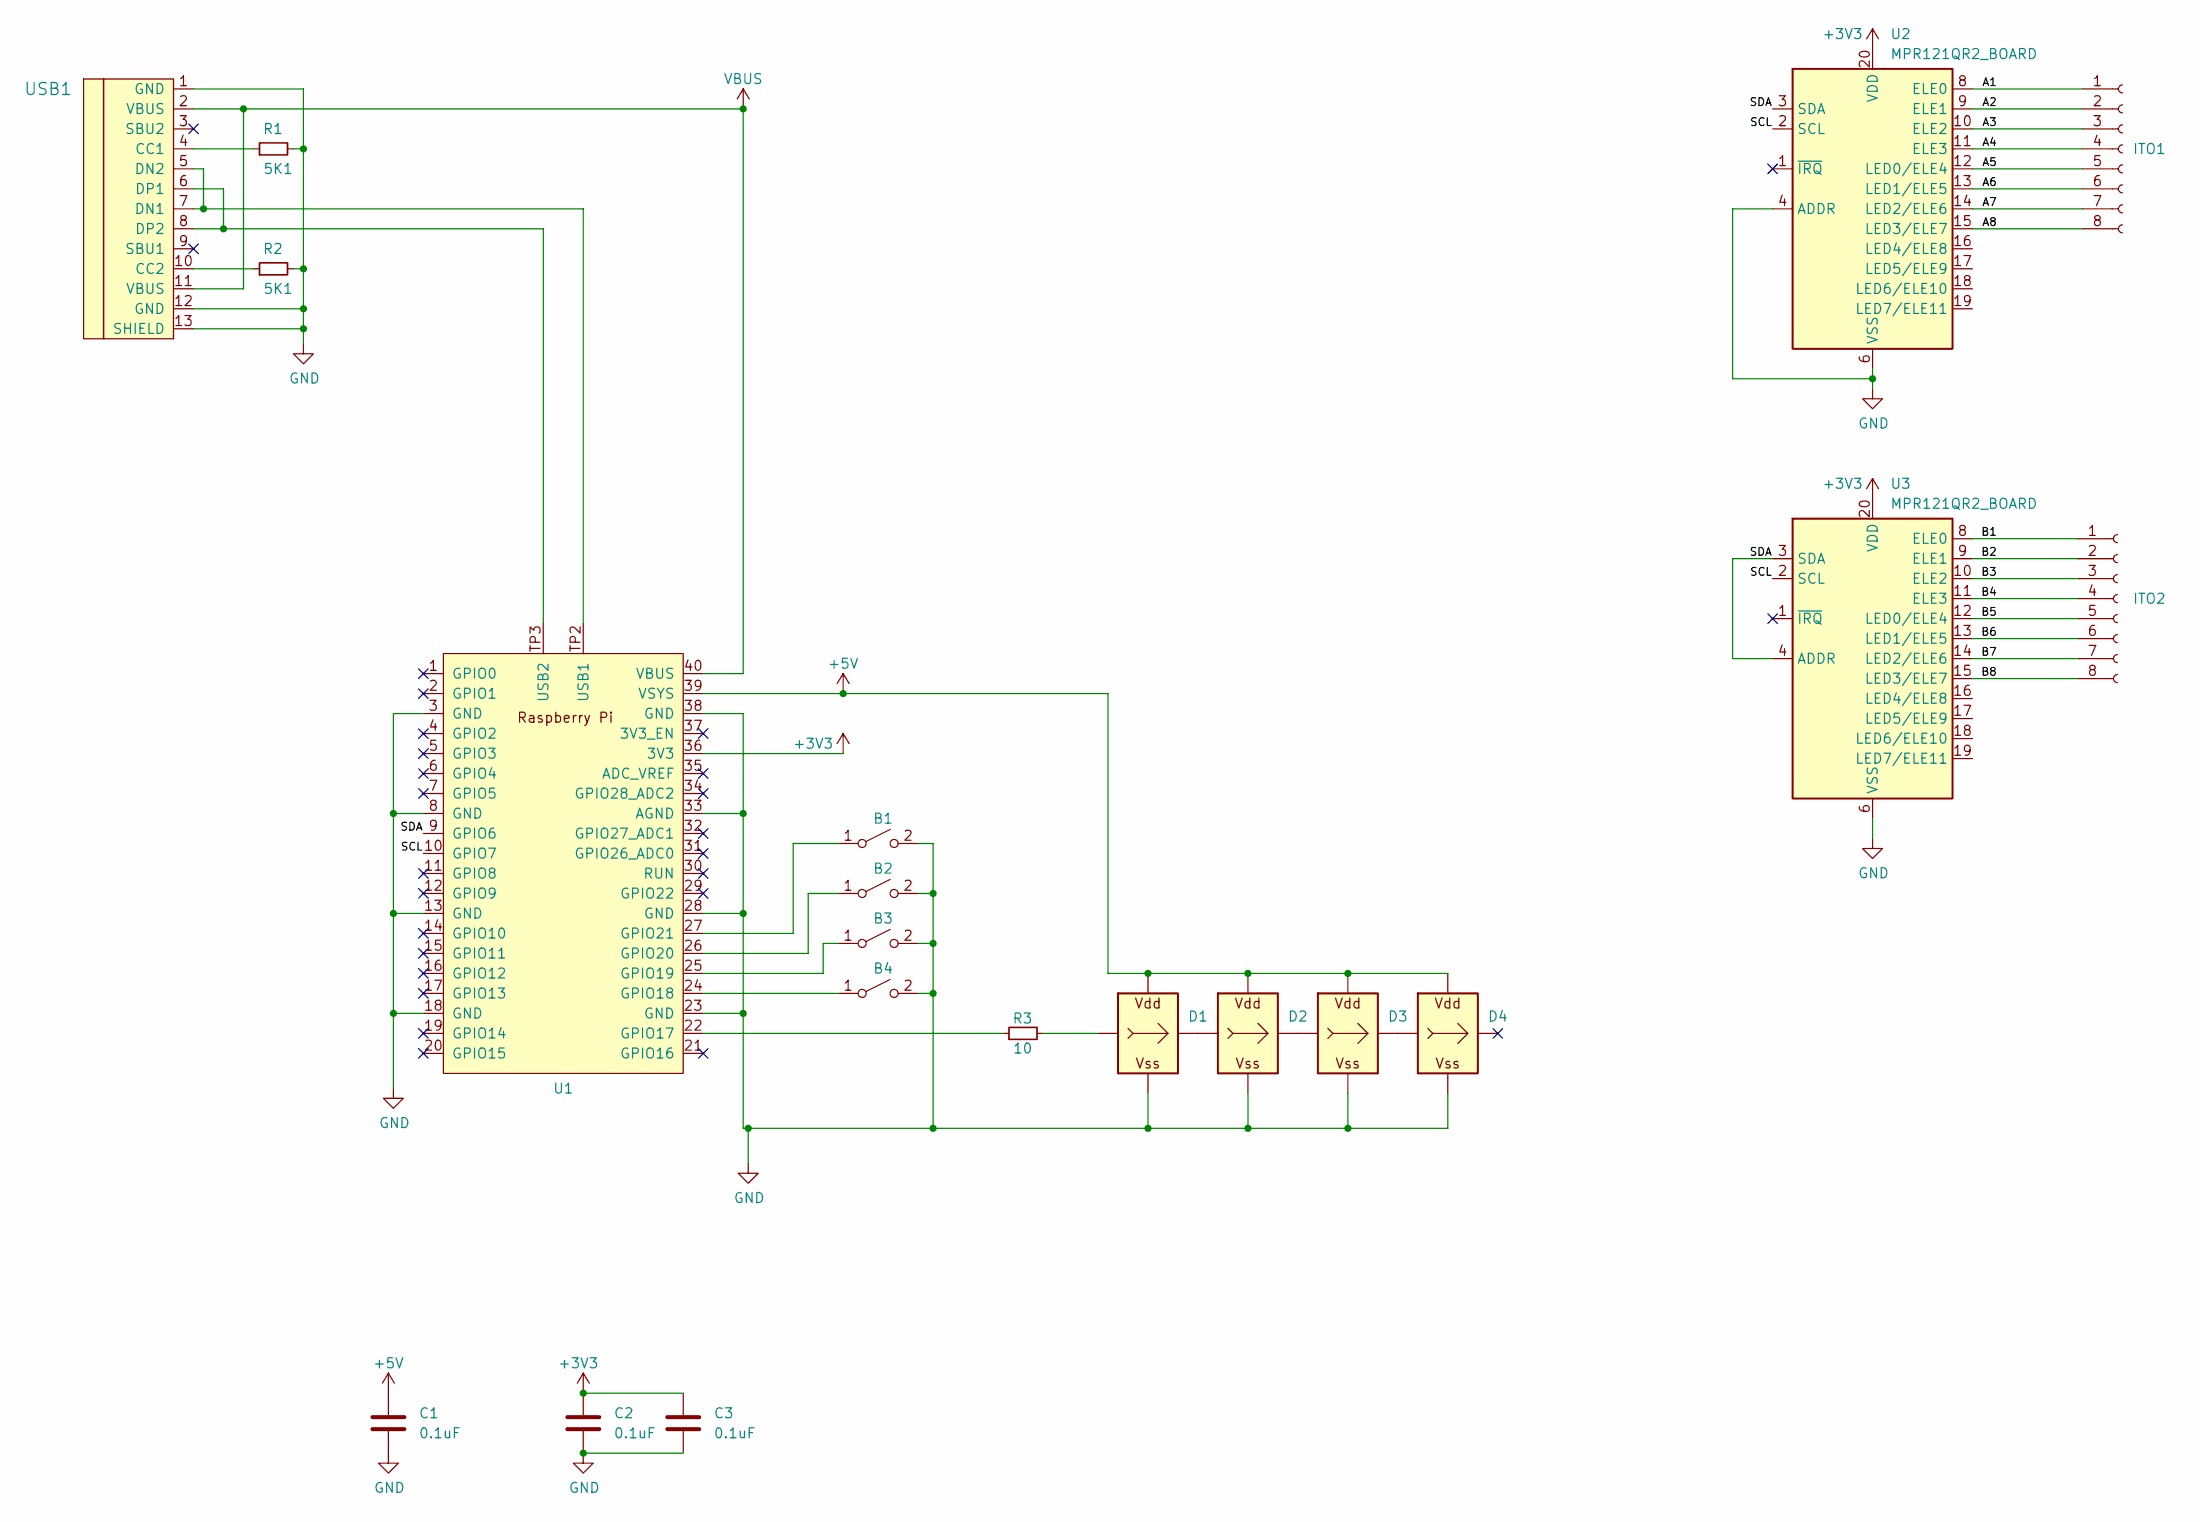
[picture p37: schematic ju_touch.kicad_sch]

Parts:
B1, B2, B3, B4: SW_SPST; EVQP1K05M
C1, C2, C3: 0.1uF; C_0603_1608Metric_Pad1.08x0.95mm_HandSolder
D1, D2, D3, D4: WS2812B_Unified; WS2812B-2835
ITO1, ITO2: Conn_01x08_Socket; JuTouch_Conn8
R1, R2: 5K1; R_0603_1608Metric_Pad0.98x0.95mm_HandSolder; LCSC C23186
R3: 10; R_0603_1608Metric_Pad0.98x0.95mm_HandSolder; LCSC C23186
U1: PiPico_No_SWD; RPi_Pico_SMD_Pins_No_SWD_No_Text
U2, U3: MPR121QR2_BOARD; MPR121_BOARD
USB1: U262-161N-4BVC11; HRO-TYPE-C-31-M-12-Assembly; LCSC C319148

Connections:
+3V3: C2.1, C3.1, U1.36 (3V3), U2.20 (VDD), U3.20 (VDD)
+5V: C1.1, D1.V (VDD), D2.V (VDD), D3.V (VDD), D4.V (VDD), U1.39 (VSYS)
/A1: ITO1.1, U2.8 (ELE0)
/A2: ITO1.2, U2.9 (ELE1)
/A3: ITO1.3, U2.10 (ELE2)
/A4: ITO1.4, U2.11 (ELE3)
/A5: ITO1.5, U2.12 (LED0/ELE4)
/A6: ITO1.6, U2.13 (LED1/ELE5)
/A7: ITO1.7, U2.14 (LED2/ELE6)
/A8: ITO1.8, U2.15 (LED3/ELE7)
/B1: ITO2.1, U3.8 (ELE0)
/B2: ITO2.2, U3.9 (ELE1)
/B3: ITO2.3, U3.10 (ELE2)
/B4: ITO2.4, U3.11 (ELE3)
/B5: ITO2.5, U3.12 (LED0/ELE4)
/B6: ITO2.6, U3.13 (LED1/ELE5)
/B7: ITO2.7, U3.14 (LED2/ELE6)
/B8: ITO2.8, U3.15 (LED3/ELE7)
/SCL: U1.10 (GPIO7), U2.2 (SCL), U3.2 (SCL)
/SDA: U1.9 (GPIO6), U2.3 (SDA), U3.3 (SDA), U3.4 (ADDR)
GND: B1.2 (B), B2.2 (B), B3.2 (B), B4.2 (B), C1.2, C2.2, C3.2, D1.G (VSS), D2.G (VSS), D3.G (VSS), D4.G (VSS), R1.2, R2.2, U1.3 (GND), U1.8 (GND), U1.13 (GND), U1.18 (GND), U1.23 (GND), U1.28 (GND), U1.33 (AGND), U1.38 (GND), U2.4 (ADDR), U2.6 (VSS), U3.6 (VSS), USB1.1 (GND), USB1.12 (GND), USB1.13 (SHIELD)
unnamed: B1.1 (A), U1.27 (GPIO21)
unnamed: B2.1 (A), U1.26 (GPIO20)
unnamed: B3.1 (A), U1.25 (GPIO19)
unnamed: B4.1 (A), U1.24 (GPIO18)
unnamed: D1.I (In), R3.2
unnamed: D1.O (Out), D2.I (In)
unnamed: D2.O (Out), D3.I (In)
unnamed: D3.O (Out), D4.I (In)
unnamed: R3.1, U1.22 (GPIO17)
unnamed: U1.TP2 (USB1), USB1.5 (DN2), USB1.7 (DN1)
unnamed: U1.TP3 (USB2), USB1.6 (DP1), USB1.8 (DP2)
unnamed: R1.1, USB1.4 (CC1)
unnamed: R2.1, USB1.10 (CC2)
VBUS: U1.40 (VBUS), USB1.2 (VBUS), USB1.11 (VBUS)

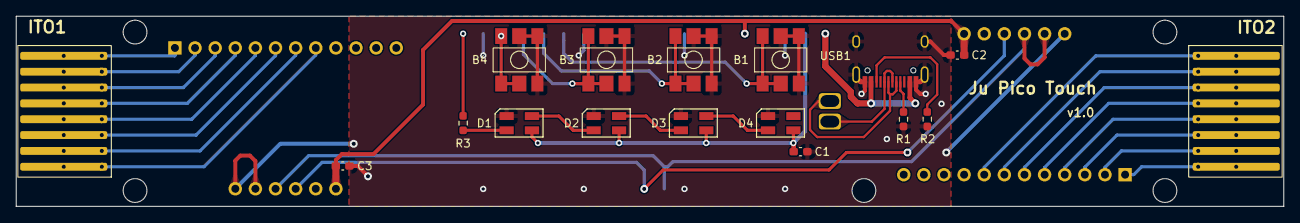
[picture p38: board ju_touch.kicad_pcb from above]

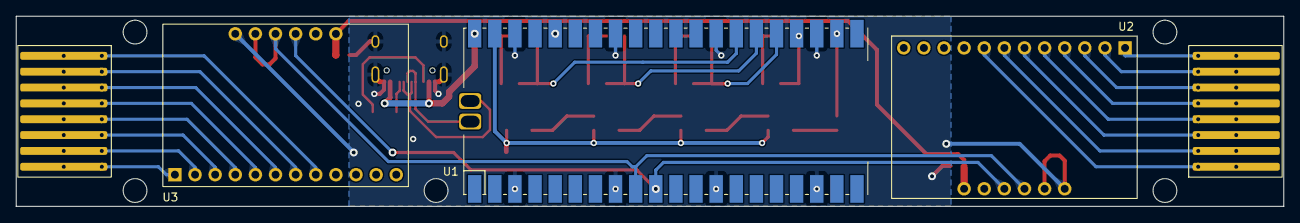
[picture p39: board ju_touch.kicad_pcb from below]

Board: 2 copper layers, 160.0 x 24.0 mm, 20 parts (5 on the bottom side), 35 nets.

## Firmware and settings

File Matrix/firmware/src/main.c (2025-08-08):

/*
 * Controller Main
 * WHowe <github.com/whowechina>
 */

#include <stdlib.h>
#include <stdint.h>
#include <stdbool.h>

#include "pico/stdio.h"
#include "pico/stdlib.h"
#include "bsp/board.h"
#include "pico/multicore.h"
#include "pico/bootrom.h"

#include "hardware/gpio.h"
#include "hardware/sync.h"
#include "hardware/structs/ioqspi.h"
#include "hardware/structs/sio.h"
#include "hardware/clocks.h"

#include "tusb.h"
#include "usb_descriptors.h"

#include "board_defs.h"

#include "button.h"

#include "save.h"
#include "config.h"
#include "cli.h"
#include "image.h"
#include "commands.h"
#include "ubthax.h"
#include "matrix.h"

static mutex_t core1_io_lock;
static void core1_loop()
{
    while (1) {
        if (mutex_try_enter(&core1_io_lock, NULL)) {
            matrix_update();
            mutex_exit(&core1_io_lock);
        } else {
            matrix_pause();
            sleep_ms(2);
        }
        sleep_us(100);
        cli_fps_count(1);
    }
}

static void runtime_ctrl()
{
    if (button_read()) {
        sleep_ms(100);
        reset_usb_boot(0, 2);
        sleep_ms(1000);
    }
}

struct __attribute__((packed)) {
    uint8_t buttons;
} hid_report = {0};

static void report_usb_hid()
{
    if (tud_hid_ready()) {
        hid_report.buttons = button_read() & 0xff;
        tud_hid_n_report(0, REPORT_ID_JOYSTICK, &hid_report, sizeof(hid_report));
    }
}

void hid_update()
{
    report_usb_hid();
}

static void core0_loop()
{
    uint64_t next_frame = time_us_64();
    while(1) {
        tud_task();

        cli_run();
        save_loop();
        cli_fps_count(0);

        button_update();
        hid_update();

        runtime_ctrl();
        ubthax_update();

        sleep_until(next_frame);
        next_frame += 1001;
    }
}

/* if certain key pressed when booting, enter update mode */
static void update_check()
{
    const uint8_t pins[] = BUTTON_DEF;
    int pressed = 0;
    for (int i = 0; i < count_of(pins); i++) {
        uint8_t gpio = pins[i];
        gpio_init(gpio);
        gpio_set_function(gpio, GPIO_FUNC_SIO);
        gpio_set_dir(gpio, GPIO_IN);
        gpio_pull_up(gpio);
        sleep_ms(1);
        if (!gpio_get(gpio)) {
            pressed++;
        }
    }

    if (pressed >= 1) {
        sleep_ms(100);
        reset_usb_boot(0, 2);
        return;
    }
}

void init()
{
    sleep_ms(50);
    board_init();

    update_check();

    set_sys_clock_khz(200000, false);

    tusb_init();
    stdio_init_all();

    config_init();
    mutex_init(&core1_io_lock);

    save_init(board_id_32() ^ 0xcafe1112, &core1_io_lock);

    button_init();

    cli_fps_label(2, "LED");

    ubthax_init();
    matrix_init();

    cli_init("ju_matrix>",
#ifdef BOARD_JU_MATRIX
             "\n       << Ju Matrix >>\n"
#else
             "\n     << Ju Matrix Plus >>\n"
#endif
            " https://github.com/whowechina\n\n");

    commands_init();

    matrix_runtime.key_stuck = button_is_stuck();
}

int main(void)
{
    init();
    multicore_launch_core1(core1_loop);
    core0_loop();
    return 0;
}

// Invoked when received GET_REPORT control request
// Application must fill buffer report's content and return its length.
// Return zero will cause the stack to STALL request
uint16_t tud_hid_get_report_cb(uint8_t itf, uint8_t report_id,
                               hid_report_type_t report_type, uint8_t *buffer,
                               uint16_t reqlen)
{
    printf("Get from USB %d-%d\n", report_id, report_type);
    return 0;
}

// Invoked when received SET_REPORT control request or
// received data on OUT endpoint ( Report ID = 0, Type = 0 )
void tud_hid_set_report_cb(uint8_t itf, uint8_t report_id,
                           hid_report_type_t report_type, uint8_t const *buffer,
                           uint16_t bufsize)
{
    if ((report_type == HID_REPORT_TYPE_FEATURE) &&
        (report_id == REPORT_ID_JUBEATHAX)) {
        ubthax_proc(buffer, bufsize);
    }
}

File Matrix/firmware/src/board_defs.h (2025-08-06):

/*
 * Ju Controller Board Definitions
 * WHowe <github.com/whowechina>
 */

#define BUTTON_DEF { 27 }

#define HUB75_DATA_BASE 0
#define HUB75_ROWSEL_BASE 6
#define HUB75_ROWSEL_N_PINS 5
#define HUB75_CLK_PIN 11
#define HUB75_STROBE_PIN 12
#define HUB75_OEN_PIN 13

#if defined BOARD_JU_MATRIX
#define PANEL_WIDTH 64
#define PANEL_HEIGHT 64
#define GRID_SIZE 13
#define GRID_GAP 4

#elif defined BOARD_JU_MATRIX_PLUS
#define PANEL_WIDTH 128
#define PANEL_HEIGHT 128
#define GRID_SIZE 23
#define GRID_GAP 12

#elif defined BOARD_JU_MATRIX_PLUS_CROP
#define PANEL_WIDTH 128
#define PANEL_HEIGHT 128
#define GRID_SIZE 27
#define GRID_GAP 8
#define GRID_OFFSET_X -2
#define GRID_OFFSET_Y -2

#endif

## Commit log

2024-10-23 Initial commit (PCB v1.0)
    [Credit Button Assy (Groovy).step, EVQ-P1D05M.stp, J 2835.step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]
2024-10-27 PCBs of v1.1
    [ju_button.kicad_pcb, ju_button_3d.step, ju_io.kicad_pcb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]
2024-11-02 PCB optimization button v1.2, io v1.21
    [PCB - PCB.dxf, ju_io.kicad_pcb, ju_io.kicad_sch]
2024-11-06 Ju Touch PCB into Ju Pico repo
    [Credit Button Assy (Groovy).step, EVQ-P1D05M.stp, J 2835.step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]
2024-11-06 Button PCB v1.2 files (missing from previous commit)
    [PCB - PCB Cut.dxf, ju_button.kicad_pcb, ju_button_3d.step]
2024-11-09 Finished guide for Ju Pico (Ju Touch not there yet)
    [ju_pico_banner.3mf, ju_pico_button_seat_40.0mm.stl, ju_pico_button_seat_40.1mm.stl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]
2024-11-10 Bambu project for banner print
    [ju_pico_banner_bambu.3mf]
2024-11-11 Screw hole and cable slot small improvement
    [ju_pico_frame.stl]
2024-11-11 More seat tolerance options
    [ju_pico_button_seat_39.8mm.stl, ju_pico_button_seat_39.9mm.stl]
2024-11-11 Connector marks in guide
2024-11-13 Screw cautions
2024-12-04 CNC and Hex nuts option
    [ju_pico_cnc_banner.step, ju_pico_cnc_frame.step, ju_pico_cnc_frame_screws.dwg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]
2024-12-06 LED Diffuser for CNC
    [ju_pico_led_diffuser_for_cnc.stl]
2025-02-12 Screw option description for the hex nut frame
2025-03-29 Frame with heat set insert option
    [ju_pico_frame_heatinsert.stl]
2025-04-28 Fix 40.0 and 40.2 button seats
    [ju_pico_button_seat_40.0mm.stl, ju_pico_button_seat_40.2mm.stl]
2025-05-12 Ju Pico IO PCB v1.22
    [ju_io.kicad_pcb, ju_io.kicad_sch]
2025-06-16 PCB folder cleanup
    [Credit Button Assy (Groovy).step, EVQ-P1D05M.stp, J 2835.step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]
2025-06-24 Change the way of button mapping
2025-07-07 LED panel working with FPS counting
2025-07-08 PCB for 21.5
    [PCB+ - PCB Cut 215.dxf, SM5B-SRSS-TB.step, ju_button215.kicad_pcb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]
2025-07-08 Geber for 21.5 button PCB
2025-07-11 dma fill for performance
2025-07-14 Button statistics
2025-08-01 Fix io conflict between save and matrix
    [hub75.c, main.c]
2025-08-04 Ju Pico better report timing
2025-08-10 Fix long trail marker
    [ubthax.c]
2025-10-21 Ju IO PCB v1.3 (just text change)
    [ju_io.kicad_pcb]
2025-12-29 Upload missing io PCB
2026-01-03 Ju Pico+ 3D files
    [ju_pico+_banner.3mf, ju_pico+_button_seat_55.2mm.stl, ju_pico+_button_seat_55.3mm.stl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]
2026-01-30 Ju Pico+ in README
2026-02-02 Add missing pico+ panel
    [ju_pico+_panel.stl]
2026-03-20 Enlarge some screw holes
    [ju_pico+_frame_inserts.stl, ju_pico_frame_inserts.stl]
